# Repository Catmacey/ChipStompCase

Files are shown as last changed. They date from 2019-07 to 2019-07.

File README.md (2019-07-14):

3d Printed Case for the [ChipStomp](https://github.com/Catmacey/ChipStomp)
=================================

This is a 3d printed case for my ChipStomp.

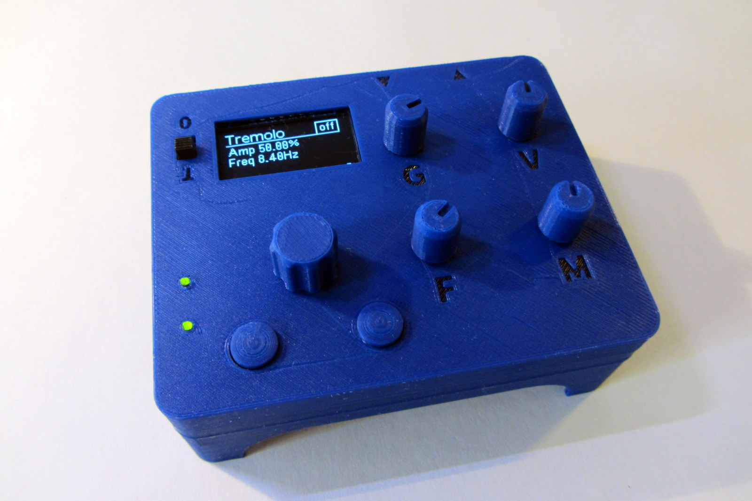
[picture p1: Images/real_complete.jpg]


The design is created in [OpenSCAD](http://www.openscad.org/) and is intended for printing using a nothing-special FDM printer with a 0.4mm nozzle.  Mine's a [ProFab Mini](http://profab3d.com/product/profab-mini-v3-3d-printer/) (an upgraded mono price mini)

The case is split into three stacking parts, the top, middle and bottom.
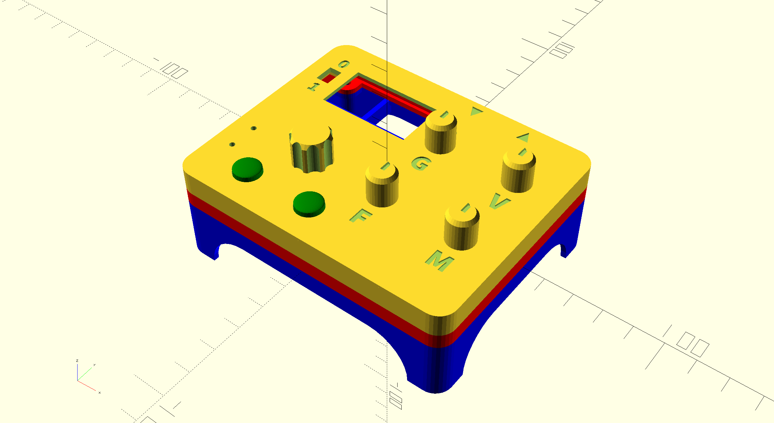
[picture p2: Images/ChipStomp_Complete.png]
ChipStomp

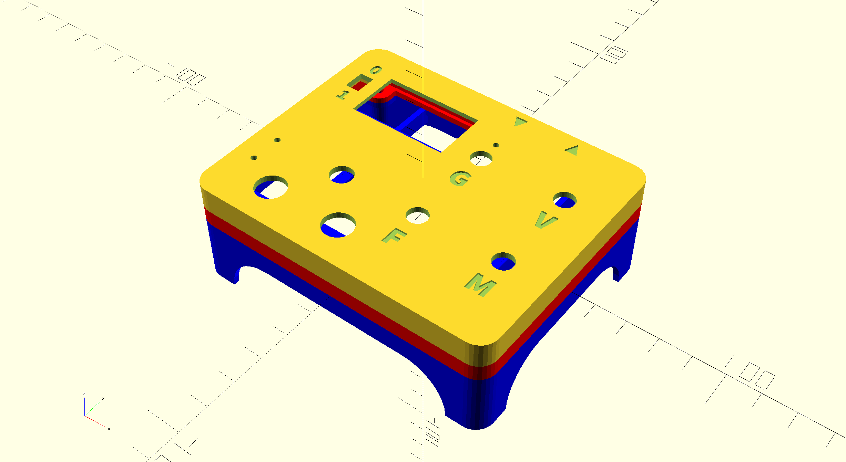
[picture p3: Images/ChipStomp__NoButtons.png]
ChipStomp

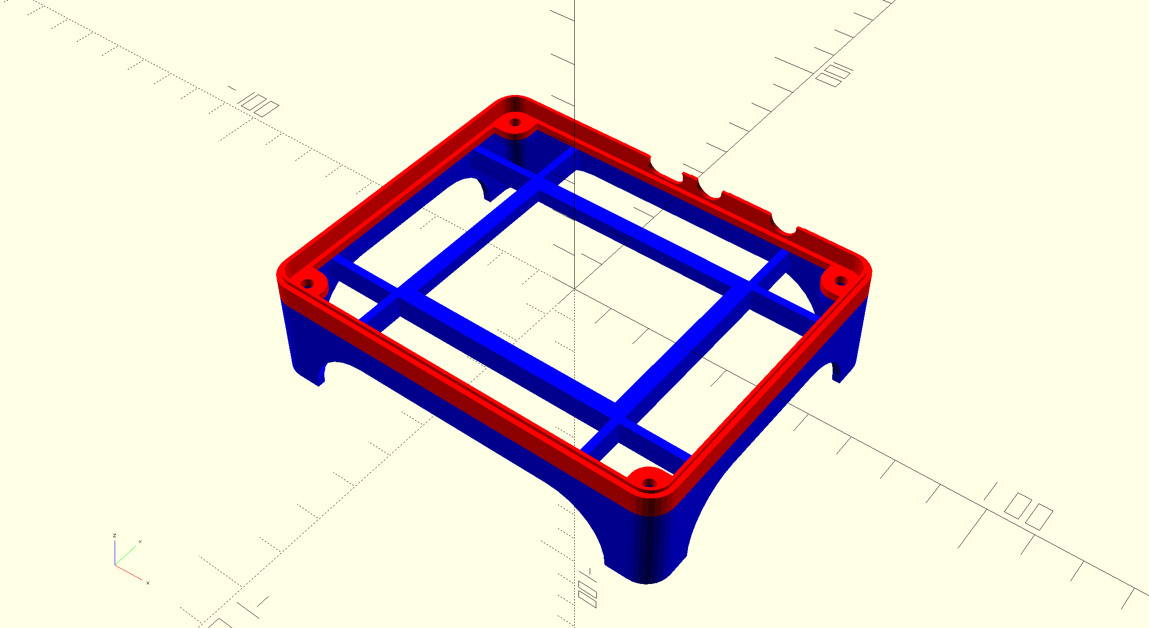
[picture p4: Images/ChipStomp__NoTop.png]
ChipStomp

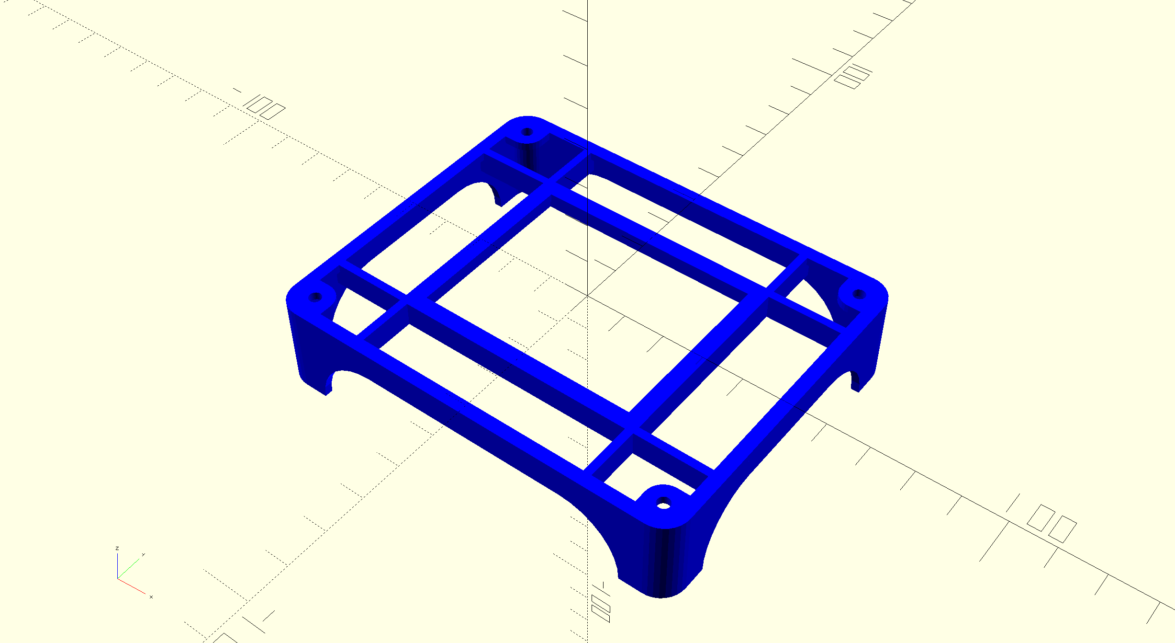
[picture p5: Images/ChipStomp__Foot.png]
ChipStomp


The case fits the Dangerous Prototypes [Sick of Beige (SOB)](http://dangerousprototypes.com/docs/Sick_of_Beige_standard_PCB_sizes_v1.0) 100x80mm PCB and is held togethjer by screws from underneath.
The lower "foot" has a space for a standard 3 cell AA battery holder.

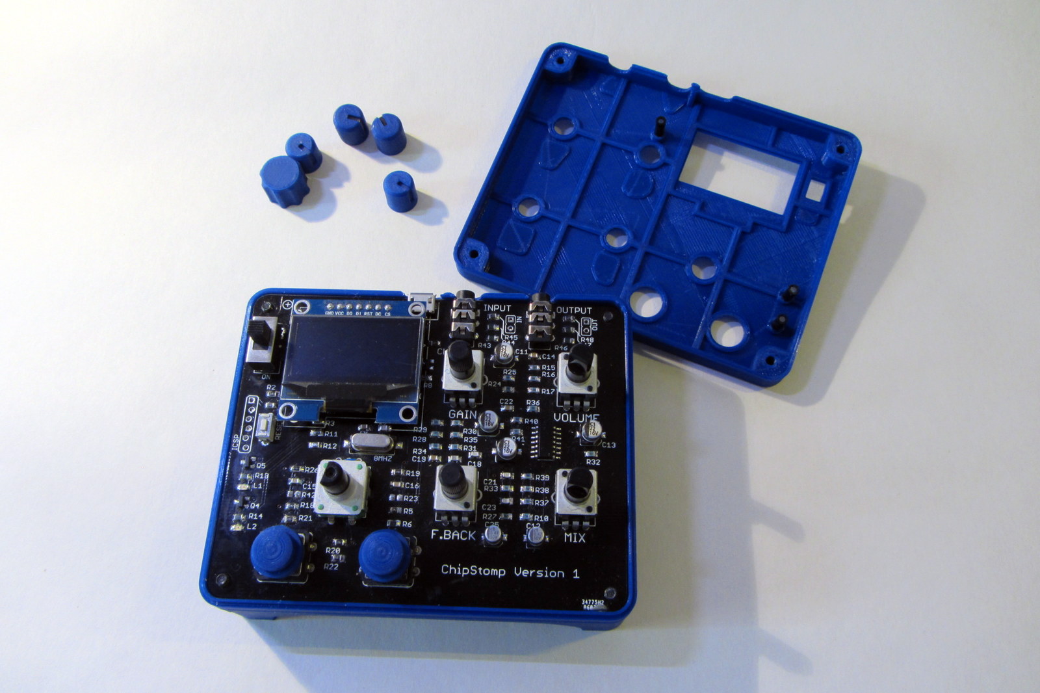
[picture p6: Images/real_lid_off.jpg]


The top contains the most detail including holes for buttons, potentiometers, the screen and leds. It also has substantial internal supporting ribs to provide more support around the holes in the top surface.

Copyright (C) 2019 Matt Casey : catmacey.com
This program is free software: you can redistribute it and/or modify it under the terms of the GNU General Public License as published by the Free Software Foundation, either version 3 of the License, or (at your option) any later version.
	
This program is distributed in the hope that it will be useful, but WITHOUT ANY WARRANTY; without even the implied warranty of MERCHANTABILITY or FITNESS FOR A PARTICULAR PURPOSE.  See the GNU General Public License for more details.

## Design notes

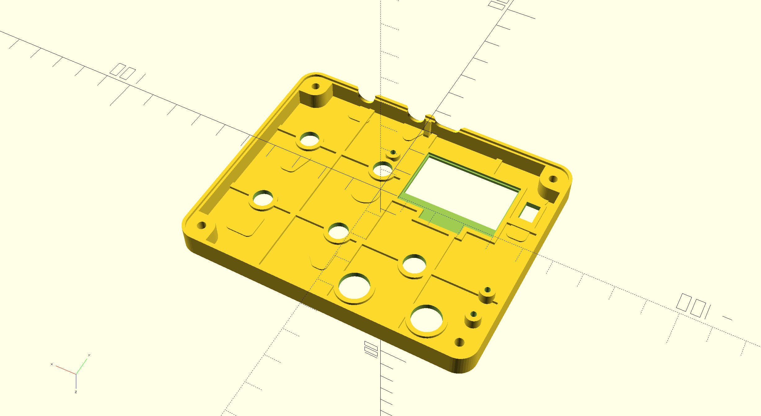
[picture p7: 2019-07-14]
Images/ChipStomp_Top_Flip.png

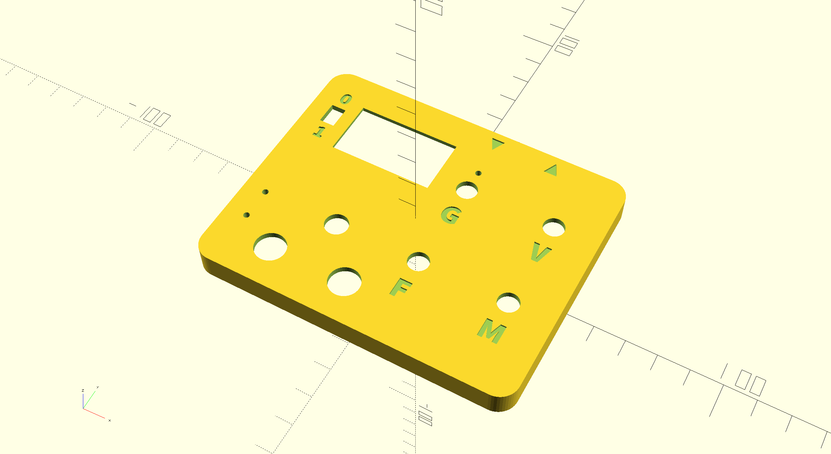
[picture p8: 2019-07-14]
Images/ChipStomp_Top.png

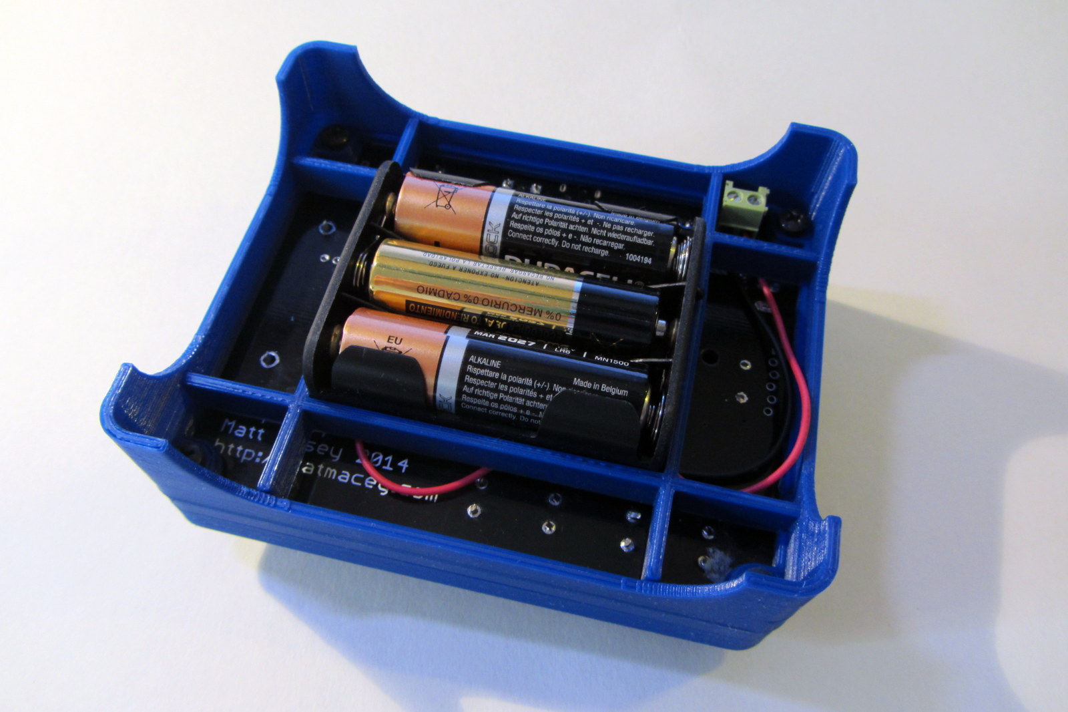
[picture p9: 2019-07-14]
Images/real_underside.jpg

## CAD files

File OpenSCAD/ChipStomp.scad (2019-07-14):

$fn=48;

// Use are self contained
use <modules/sob_pcb.scad>;
use <modules/helpers.scad>;
use <modules/buttons.scad>;
use <modules/knob.scad>;



// dp_sob_100x80_base
nozzle = 0.4;
// Ideal printable wall thickness 
// Should be multiple of nozzle width for best results
wall_thick = (nozzle * 5);

// Overlapping wall lip thicknesses 
wall_lip_inner = wall_thick * 0.4;
wall_lip_outer = wall_thick - wall_lip_inner;

// PCB dimensions
pcb_w = 100; // width
pcb_h = 80; // height
pcb_t = 1.6; // thickness
pcb_hole_r = 1.6; // mounting hole radius
pcb_hole_off = 4; // mounting hole offset
pcb_corner_r = 4; // corner radius
pcb_tolerance = 0.25; // How much space to allow for over sized PCBs

// Overall widths of box shell
box_inner_w = pcb_w + (pcb_tolerance*2);
box_outer_w = box_inner_w + (wall_thick*2);
box_inner_h = pcb_h + (pcb_tolerance*2);
box_outer_h = box_inner_h + (wall_thick*2);
box_lip_w = box_inner_w + (wall_lip_inner*2); 
box_lip_h = box_inner_h + (wall_lip_inner*2);

box_inner_r = pcb_corner_r + pcb_tolerance;
box_outer_r = pcb_corner_r + pcb_tolerance + wall_thick;
box_lip_r = pcb_corner_r + pcb_tolerance + wall_lip_inner;

wall_lip_height = 1;
foot_height = 2;
middle_height = 5.5;

// How much vertical space the electronics have inside the middle/top enclosure from the top of the middle foot (eg the underside of PCB) to the underside of the top surface (not including ribs)
middle_top_internal_height = 11;

top_ceiling = middle_top_internal_height + foot_height - middle_height; // How much inner height belongs to the top
top_face_thick = 1;
top_rib_thick = 1;

drill_r = 1.5;
corner_pad_r = pcb_hole_off + pcb_tolerance + pcb_tolerance;

// Positions of in/outs on back side
// heights are from PCB top surface
jack_in = 57.8;
jack_out = 77.8;
jack_height = 2.65;
jack_clear_r = 3.5;
usb_center = 45.72;
usb_clear_w = 10;
usb_clear_r = 2.5;
usb_height = 1.5;

// Position of twiddlers on the top
pot_rad = 3.4;
top_holes = [
		// x, y, radius, label, supportdepth
		[58.42, 22.86, pot_rad, "F"] // Feedback
	, [87.63, 22.86, pot_rad, "M"] // Mix
	,	[58.42, 53.34, pot_rad, "G"] // Gain
	, [87.63, 53.34, pot_rad, "V"] // Volume
	, [30.48, 53.34, 3.8] // encoder
	, [17.78, 69.85, 5] // button 1
	, [43.18, 69.85, 5] // button 2
	, [5.08, 53.34, 1, undef, 4] // led 1
	, [5.08, 63.5, 1, undef, 4] // led 2
	, [58.42, 15.24, 1, undef, 2] // clipled
];
// x, y, w, h
top_squares = [
		// [30.48, 20.32 ,35.5, 23.5] // screen
		[
			// screen
			30.48, 18.5, 34, 19, // outer hole (in the surface)
			30.48, 20.25, 35, 23.5, //inner hole (for clearance)
			30.48, 33, 15, 6// 15mm Clearance for flex cable
		] 
	, [6.55, 16.51, 5, 7.5] // switch
];

// Labels
labels = [
		[6.55, 16.51-8, "0", 5] // off
	, [6.55, 16.51+8, "1", 5] // on
	, [jack_in, 2.5, "▼", 4] // in
	, [jack_out, 2.5, "▲", 4] // out
	// , [62, 15.24, "!"] // clip
];


// Button height above PCB surface (including height of tactile)
tactile_height = 4.5;
button_z_offset = tactile_height + pcb_t + foot_height;
// Internal height
button_base_height = middle_top_internal_height-(pcb_t+tactile_height+top_rib_thick);
// external height
button_top_height = top_rib_thick + top_face_thick + 2;
// Translation


// The PCB (Handy for visualizing)
*translate([0,0,foot_height]){
	sob_pcb(width=pcb_w, height=pcb_h, thickness=pcb_t);
}


// Build the model
top();
// middle();
// bottom();
// A knurled knob
*translate([conv_x(30.48), conv_y(53.34), middle_top_internal_height+top_face_thick+top_rib_thick+1.5])
	knob(
			shaft_rad=3
		, shaft_depth=9
		, outer_rad=7
		, key_depth=7
		, knurled=8
		, centerpoint=false
	)
;
// Potentiometer knows
*translate([conv_x(58.42), conv_y(22.86), middle_top_internal_height+top_face_thick+top_rib_thick+1.5])
	knob(shaft_rad=3, shaft_depth=9, outer_rad=5, key_depth=7)
;
*translate([conv_x(87.63), conv_y(22.86), middle_top_internal_height+top_face_thick+top_rib_thick+1.5])
	knob(shaft_rad=3, shaft_depth=9, outer_rad=5, key_depth=0)
;
*translate([conv_x(58.42), conv_y(53.34), middle_top_internal_height+top_face_thick+top_rib_thick+1.5])
	knob(shaft_rad=3, shaft_depth=9, outer_rad=5, key_depth=7)
;
*translate([conv_x(87.63), conv_y(53.34), middle_top_internal_height+top_face_thick+top_rib_thick+1.5])
	knob(shaft_rad=3, shaft_depth=9, outer_rad=5, key_depth=0)
;

// Don't need to see the buttons normally
*translate([conv_x(17.78), conv_y(69.85), button_z_offset]){
	color("green")
	button_cyl(
			4.8
		,	3.5
		,	6
		,	button_base_height
	);
}
*translate([conv_x(43.18), conv_y(69.85), button_z_offset]){
	color("green")
	button_cyl(
			4.8
		,	3.5
		,	6
		,	button_base_height
	);
}


// Includes have access to variables declare in here
include <includes/modules_include.scad>;
// separate parts
include <includes/inc_top.scad>;
include <includes/inc_middle.scad>;
include <includes/inc_bottom.scad>;

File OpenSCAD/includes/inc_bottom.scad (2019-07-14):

// Needs to be included

//Bottom feet of the box with central space for a standard 3 AA cell battery holder
module bottom(){
	// Battery box dims
	batt_w = 58;
	batt_h = 47;
	// depth of bracing
	supp_thick = 6;
	color("blue")
	union(){
		// Lip for battery box
		translate([0,0,-2])
		linear_extrude(2, convexity = 10){
			difference(){
				square([batt_w,batt_h],true);
				square([batt_w-(wall_thick*2),batt_h-(wall_thick*2)],true);
			}
		};

		translate([0,0,-supp_thick])
		linear_extrude(supp_thick, convexity = 10){
			// horiz supports
			translate([0,(batt_h/2)+(wall_thick/2),0]) square([box_inner_w, wall_thick], true);
			translate([0,-((batt_h/2)+(wall_thick/2)),0]) square([box_inner_w, wall_thick], true);
			// Vertical supports
			translate([(batt_w/2)+(wall_thick/2),0,0]) square([wall_thick, box_inner_h], true);
			translate([-((batt_w/2)+(wall_thick/2)),0,0]) square([wall_thick, box_inner_h], true);
		};

		translate([0,0,-foot_height]){
			cornerpads(
				width=corner_pad_r,
				height=foot_height,
				drill=drill_r
			);
			// Inner lip
			linear_extrude(foot_height, convexity = 10){
				difference(){
					rounded_rectangle(box_outer_w,box_outer_h,box_outer_r);
					rounded_rectangle(pcb_w-wall_thick, pcb_h-wall_thick, box_inner_r);
				}
			}
			// wall
			translate([0,0,-20])
			render()
			difference(){
				linear_extrude(20, convexity = 10){
					difference(){
						rounded_rectangle(box_outer_w,box_outer_h,box_outer_r);
						rounded_rectangle(box_inner_w, box_inner_h, box_inner_r);
					}
				}
				chop_rad = 15;
				chop_space = 12;
				chop_extra = 8;
				rotate([0,90,0])
				hull(){
					translate([0,-((box_outer_h/2)-chop_rad-chop_space),0])
					cylinder(h=box_outer_w+chop_extra, r=chop_rad, center=true);
					translate([0,((box_outer_h/2)-chop_rad-chop_space),0])
					cylinder(h=box_outer_w+chop_extra, r=chop_rad, center=true);
				}
				rotate([90,0,0])
				hull(){
					translate([-((box_outer_w/2)-chop_rad-chop_space),0,0])
					cylinder(h=box_outer_h+chop_extra, r=chop_rad, center=true);
					translate([((box_outer_w/2)-chop_rad-chop_space),0,0])
					cylinder(h=box_outer_h+chop_extra, r=chop_rad, center=true);
				}
			}
		}
	}
}

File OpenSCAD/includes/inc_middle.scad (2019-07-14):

// Middle part of the box
module middle(){
	color("red")
	render()
	difference(){
		union(){
			cornerpads(
				width=corner_pad_r,
				height=foot_height,
				drill=drill_r
			);

			// top lip
			translate([0,0,middle_height])
			linear_extrude(wall_lip_height, convexity = 10){
				difference(){
					rounded_rectangle(
							box_lip_w
						, box_lip_h
						, box_lip_r
					);
					rounded_rectangle(
							box_inner_w
						, box_inner_h
						, box_inner_r
					);
				}
			};

			// Wall
			if(middle_height-foot_height > 0){
				translate([0,0,foot_height])
				linear_extrude(middle_height-foot_height, convexity = 10){
					difference(){
						rounded_rectangle(box_outer_w,box_outer_h,box_outer_r);
						rounded_rectangle(box_inner_w, box_inner_h, box_inner_r);
					}
				};
			}
			// inner lip
			linear_extrude(foot_height, convexity = 10){
				difference(){
					rounded_rectangle(box_outer_w,box_outer_h,box_outer_r);
					rounded_rectangle(pcb_w-wall_thick, pcb_h-wall_thick, pcb_corner_r);
				}
			}
		}
		// Clearance for the Jacks
		jack_holes(height=foot_height+pcb_t);
	};
}

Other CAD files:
OpenSCAD/includes/inc_top.scad
OpenSCAD/includes/modules_include.scad
OpenSCAD/modules/buttons.scad
OpenSCAD/modules/helpers.scad
OpenSCAD/modules/knob.scad
OpenSCAD/modules/sob_pcb.scad

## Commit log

2019-07-14 Initial import of project
    The entire project
    [ChipStomp.scad, buttons.scad, helpers.scad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]
2019-07-14 Link to Dangerous Prototypes SOB standard
